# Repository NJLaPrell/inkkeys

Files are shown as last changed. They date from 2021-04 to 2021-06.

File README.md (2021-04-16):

# inkkeys
Details and instructions can be found on https://there.oughta.be/a/macro-keyboard

In contrast to most of my other projects, I decided to put this into its own repository as it is slightly more complex and I am hoping for community contributions.

If you have pull-requests, bug reports or want to contribute new case designs, please do not hesitate to open an issue. For generic discussions, "show and tell" and if you are looking for support for something that is not a problem in the code here, I would recommend [r/thereoughtabe on reddit](https://www.reddit.com/r/thereoughtabe/).

## Mac Install
Installing on the mac requires several dependencies, some of which are not apparent without a little digging. In order for the AppKit dependency to properly compile, you must be using Python 3.3.* or higher. Note that pulse audio is linux only, so it must be commented/removed from the python code. You will not be able to install the dependency. The following commands should mostly put everything in order to run the controller.py script.

    brew install pkg-config
    brew install cairo
    pip3 install pillow
    pip3 install pyserial
    pip3 install psutil
    pip3 install AppKit
    pip3 install pyobjc

## Common problems

**NOTE:** This fork already has the changes below implemented.

### Display revision 2
Apparently, the original design used revision 1 of the display, while many newly ordered version are revision 2. There are a few differences and thankfully, [Corky402 made a good list of required changes on Reddit](https://www.reddit.com/r/arduino/comments/l4wxxf/the_hardware_is_assembled_and_passed_all_tests/gqovq1j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). 

Here is an excerpt of the original post for reference:
>If you want to test your display hooked to a Arduino or Raspberry Pi you need to run examples for the epd2in9_V2 not the epd2in9.
>
>To get this awesome project working there is no need to make any alterations to the PCB, just simply plumb the Waveshare up on the connectors as I describe, not as per Sebastian's original post.
>
>PCB Pin Waveshare wiring loom
>
>+5v Grey
>
>GND Brown
>
>DIN Blue
>
>CLK Yellow
>
>CS Orange
>
>DC Green
>
>RST Purple
>
>BUSY White
>
>In short you are swapping the RST & BUSY lines on the PCB.
>
>Next, go to your Arduino sketch. This is for the hardware-test script. Enable line numbering and go to line 43 which reads -
>
>GxEPD2_290 display(/*CS=*/ PIN_CS, /*DC=*/ PIN_DC, /*RST=*/ PIN_RST, /*BUSY=*/ PIN_BUSY);
>
>Change this to -
>
>GxEPD2_290_T94 display(/*CS=*/ PIN_CS, /*DC=*/ PIN_DC, /*RST=*/ PIN_RST, /*BUSY=*/ PIN_BUSY);
>
>Then go to settings.h
>
>Lines 2 - 7 need to be altered so change that section of code as follows -
>
>const byte PIN_DIN = 16;
>
>const byte PIN_CLK = 15;
>
>const byte PIN_CS = 19;
>
>const byte PIN_DC = 18;
>
>const byte PIN_RST = 10;
>
>const byte PIN_BUSY = 14;
>
>The sketch will then compile and when uploaded to the board you will get the Waveshare drawing all sorts of Austin Powers time machine circles that make your eyes spin! 

### Alternate Neopixels ###
If a different LED is substituted for the PL9823, the usage in the led.ino file and hardware-test.ino file may be different. For the APA106 LED, the NeoPixels are initialized this way:

    Adafruit_NeoPixel leds = Adafruit_NeoPixel(N_LED, PIN_LED, NEO_GRB + NEO_KHZ800);

### Serial Hang ###
An instance using a Mac and the YeeKees Pro Micro controller encountered issues where sending binary data resulted in the Pro Micro no longer recieving  serial data (but sill sending). It is unknown at this time if the issue is how pyserial is implimented on Mac or a limitation of the YeeKees Pro Micro controller (two different controllers yielded the same issue). The workaround is to chunk the byte data and send it 100 bytes at a time.

### E-Ink Display Issues ###
E-ink display renders icons faded in some cases and missing pixels in others. Cause is unknown at this time and may be related to timing. 

## Gallery

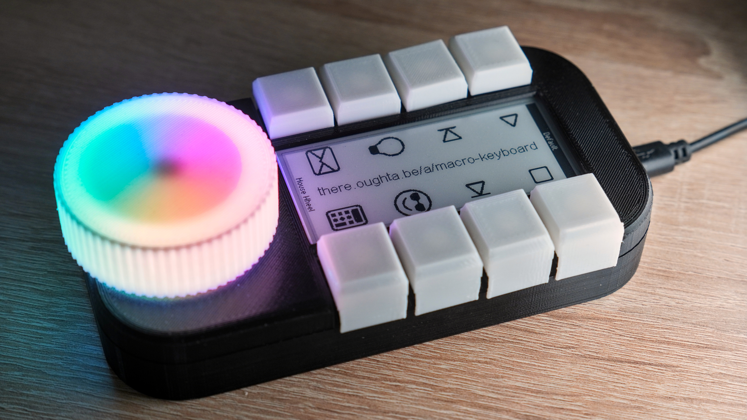
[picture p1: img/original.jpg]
Original design Original design as presented on there.oughta.be with the 3d printing files from this repository.

Original design as presented on there.oughta.be with the 3d printing files from this repository.

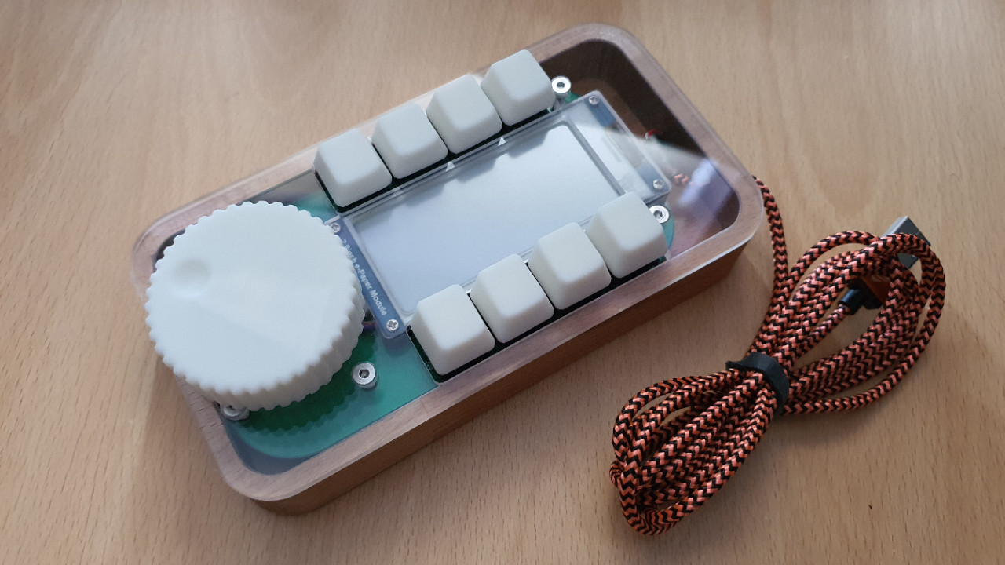
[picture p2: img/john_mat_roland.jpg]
Original design Design by John, Mat and Roland from the UK. The case was CNC milled from beech with a similarly machined clear perspex lid.

Design by John, Mat and Roland from the UK. The case was CNC milled from beech with a similarly machined clear perspex lid.

## Fork Notes ##
This fork uses a KeeYees brand Pro Micro controller and APA106 LEDs which are different from the original specs. The python code is also run on a Mac and has been updated to rotate the display 90 degrees so that the device can be rotated on it's side. This is a work in progress.

### Known Issues ###
 - The text for the title must have a minimum height of 40 or the controller goes unresponsive and responds with unknown characters when the display is refreshed.
 - Resending images often times out and has the effect of fading the current display when the display is shut down.

### TODO ###
 - Re-impliment the icon overlays.
 - Re-impliment the ability to use text instead of icons.
 - Add the ability to place text above/below the icons.

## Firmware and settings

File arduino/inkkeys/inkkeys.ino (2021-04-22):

/*
 * E-Ink adaptive macro keyboard
 * See https://there.oughta.be/a/macro-keyboard
 * 
 * This is the main code which acts as a HID keyboard while
 * allowing to be controlled through a serial interface.
 */

#include "settings.h"           //Customize your settings in settings.h!

#include "eventsequence.h"      //Structure and constants to define the sequence of events assigned to different buttons
#include <HID-Project.h>        //HID (Keyboard/Mouse etc.)
#include <Encoder.h>            //Rotary Encoder
#include <GxEPD2_BW.h>          //E-Ink Display
#include <Adafruit_NeoPixel.h>  //Digital RGB LEDs

//Keys
const byte nSW = 9;
const byte SW[] = {PIN_SW1, PIN_SW2, PIN_SW3, PIN_SW4, PIN_SW5, PIN_SW6, PIN_SW7, PIN_SW8, PIN_SW9}; //Array of switches for easy iteration
bool pressed[] = {false, false, false, false, false, false, false, false, false}; //Last state of each key to track changes
uint32_t swDebounce[] = {0L, 0L, 0L, 0L, 0L, 0L, 0L, 0L, 0L};

//Rotary encoder
Encoder rotary(PIN_ROTA, PIN_ROTB);
long rotaryPosition = 0;  //Last position to keep track of changes

//Display
//GxEPD2_290 display(/*CS=*/ PIN_CS, /*DC=*/ PIN_DC, /*RST=*/ PIN_RST, /*BUSY=*/ PIN_BUSY);
GxEPD2_290_T94 display(/*CS=*/ PIN_CS, /*DC=*/ PIN_DC, /*RST=*/ PIN_RST, /*BUSY=*/ PIN_BUSY);
//GxEPD2_290_T94<GxEPD2_290_T94, GxEPD2_290_T94::HEIGHT> display(GxEPD2_290_T94(/*CS=*/ PIN_CS, /*DC=*/ PIN_DC, /*RST=*/ PIN_RST, /*BUSY=*/ PIN_BUSY));
void initDisplay() {
  display.init(115200, true, 1, false);
  display.writeScreenBuffer();
  display.refresh();
  display.writeScreenBufferAgain();
  display.powerOff();
}

void setup() {
  initLEDs();
  //Initialize LEDs first, for some reason they initialize blue
  //  after a power cycle which is pretty annoying.
  
  Serial.begin(115200);

  defaultAssignment();

  //Greeting on serial
  Serial.println("= InkKeys =");
  
  //Set pin modes for keys
  for (int i = 0; i < nSW; i++) {
    pinMode(SW[i], INPUT_PULLUP);
  }

  //Set rotary encoder to zero
  rotary.write(rotaryPosition);

  //Init e-ink screen, clear it and turn it off.
  initDisplay();

  //Init HID.
  //These three should provide most desired functions and as the 32u4
  //on the Pro Micro provides 6 endpoints (-1 for serial), we can
  //use the single report variants for compatibility.
  BootKeyboard.begin();
  BootMouse.begin();
  SingleConsumer.begin();

  //Show LED greeting to confirm completion
  animateLeds(1, 800, 10, 0, (0, 0, 0), 1);
  Serial.println("Ready.");
}

void loop() {
  processAnimation();
  checkKeysAndReportChanges();
  checkRotaryEncoderAndReportChanges();
  handleSerialInput();
}

//Called when state of key has changed. Checks debounce time
//and returns false if event should be filtered. Otherwise it
//returns true and resets the debounce timer.
bool debounce(byte i) {
  long t = millis();
  if (t - swDebounce[i] < DEBOUNCE_TIME)
    return false;
  else {
    swDebounce[i] = t;
    return true;
  }
}

//Check if keys have changed and report any changes
void checkKeysAndReportChanges() {
  for (int i = 0; i < nSW; i++) {
    int state = digitalRead(SW[i]);
    if (state == LOW && !pressed[i]) {
      if (debounce(i)) {
        pressed[i] = true;
        Serial.print(i+1);
        Serial.println("p");
        executeEvents(assignments[i][0]);
      }
    } else if (state == HIGH && pressed[i]) {
      if (debounce(i)) {
        pressed[i] = false;
        Serial.print(i+1);
        Serial.println("r");
        executeEvents(assignments[i][1]);
      }
    }
  }
}

//Check if rotary encoder position changed and report any changes
void checkRotaryEncoderAndReportChanges() {
  long rotaryNew = rotary.read();
  if (abs(rotaryNew - rotaryPosition) >= ROT_FACTOR) {
    int report = (rotaryNew-rotaryPosition)/ROT_FACTOR;
    Serial.print("R");
    Serial.println(report);
    rotaryPosition += report*ROT_FACTOR;
    for (int i = 0; i < report; i++)
      executeEvents(assignments[9][0]);
    for (int i = 0; i < -report; i++)
      executeEvents(assignments[9][1]);
  }
}

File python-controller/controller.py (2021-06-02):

SERIALPORT = None #None = Auto-detect, to specify a specific serial port, you can set it to something like "/dev/ttyACM0" (Linux) or "COM1" (Windows)
VID = 0x1B4F      #USB Vendor ID for a Pro Micro
PID = 0x9206    #USB Product ID for a Pro Micro
DEBUG = True     #More output on the command line
HTTP_PORT = 8080

from inkkeys import *        #Inkkeys module
from processchecks import *  #Functions to check for active processes and windows
from modes import *          #Definitions of the hotkey functions in different "modes"

import time                         #Time functions
from serial import SerialException  #Serial functions
import serial.tools.list_ports      #Function to iterate over serial ports
import re                           #Regular expressions process name matching
import traceback                    #Print tracebacks if an error is thrown and caught
import socket                       #Get the hostname of the computer

import json
import threading                    #Run an http server in a separate thread.
from http.server import HTTPServer, BaseHTTPRequestHandler
from json import JSONDecodeError

print("https://there.oughta.be/a/macro-keyboard")
print('I will try to stay connected. Press Ctrl+c to quit.')

class HttpHandler(BaseHTTPRequestHandler):  
    def do_POST(self):
        content_length = int(self.headers["Content-Length"])
        post_data = self.rfile.read(content_length)
        if DEBUG:
            print(f"POST - {content_length} bytes received.")
        try:
            payload = json.loads(str(post_data, "utf-8"))
            if "status" in payload:
                device.setStatus(payload["status"])

            self.send_response(200)
            self.send_header("Content-type", "text/plain")
            self.end_headers()
        except JSONDecodeError as jde:
            print(jde)
            print(post_data)
            self.send_response(200)
            self.send_header("Content-type", "text/plain")
            self.end_headers()

def listenToHttp():
    print(f'Listening for http traffic on port {HTTP_PORT}')
    try:
        httpd = HTTPServer(("0.0.0.0", HTTP_PORT), HttpHandler)
        httpd.serve_forever()
    except OSError:
        print(f"Cannot bind http server on adress {HTTP_PORT}")

httpThread = threading.Thread(target=listenToHttp, daemon=True)
httpThread.start()



############################################################################################################

#This is the main part, which reassigns keys, sets the content of the display and updates the LEDs.
#The logic of this is built around "modes". The modes themselves are defined in "modes.py", where you can
#change key assignments, images, LED animations and their entire logic.

#Below, you only define a list of modes (defined in "modes.py") that are active and set either a process
#(mode would be active whenever the process runs) or an active window (mode is active if the window has
#the focus. The latter is a compiled regular expression pattern. Mode priority corresponds to the order in the
#list, so the first mode with a matching process or active window will be activated.

modes = [\
            {"mode": ModeBlender(), "activeWindow": re.compile("^Blender")}, \
            {"mode": ModeGimp(), "activeWindow": re.compile("^GIMP.*")}, \
            {"mode": ModeMiniFallback(), "hostname": re.compile("^Mac-Min.*")}, \
            {"mode": ModeFallback()} \
        ]

hostname = socket.gethostname()

############################################################################################################

# Usually there should not be anything to be customized below this point

############################################################################################################

#If we found the device, successfully connected and retreived its information, we enter this work function,
#which primarily consists of an infinite loop that only returns if we hit Ctrl+C (or kill the process).

def work():
    mode = None             #Current mode of the device (i.e. key mappings for specific process).
    pollInterval = 0        #Polling interval as requested by the module when the last call to "poll" was made
    lastPoll = 0            #Keeps track of the last time the poll function of the mode instance was called
    lastProcessList = 0     #Keeps track of the last time the list of processes was retrieved
    lastModeCheck = 0       #Keeps track of the last time the current window was checked and a decision about the mode was made
    activeWindow = None
    
    try:
        while True:     #Now we are in our main, infinite loop -------------------
            now = time.time() #Time of this iteration

            if now - lastProcessList > 5.0:      # Only check the process list every 5 seconds.
                processes = getActiveProcesses() # This is a surprisingly expensive and slow call, so don't overdo as it might prevent smooth LED animation (fixable by implementing a second thread) and burn more CPU resources than you might want from a background process
                lastProcessList = now

            if now - lastModeCheck > 0.5:       # Check active window and decide which mode to use. This can be done more regularly, but since the e-ink screen takes a moment to update, it does not make sense to check more frequently
                window = getActiveWindow()      # Get the currently active window
                if window != None:              # Sometime getting the active window fails, then ignore it. (Some window managers allow having no window in focus)
                    if DEBUG and activeWindow != window:                   #Enable DEBUG to see the actual name of the current window if you need it to match your modules
                        print("Active window: " + str(window))
                    activeWindow = window
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

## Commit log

2021-04-03 Included pin change for v2 display.
2021-04-03 Pin change in both settings files for v2 display...
2021-04-03 Changed LED to APA106 instead of PL9823.
2021-04-03 Change solder mask and added gbr files generated for the PCB ordered through JLCPCB.
    [inkkeys-B_Mask.gbr, inkkeys-B_Paste.gbr, inkkeys-B_SilkS.gbr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]
2021-04-13 Resolved serial hang and some display issues.
    [controller.py, device.py, modes.py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]
2021-04-14 Progress fixing display ghosting. Start of modifications for my own use.
    [controller.py, device.py, inkkeys.ino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]
2021-04-14 More button assignments
2021-04-21 Fixed mode detection for hostname. Updated the way the screen is cleared when switching hosts. Defaulted refreshDisplay not to rewrite back to the buffer when no partial refreshes will happen later.
    [controller.py, device.py, serialinput.ino]
2021-04-22 Converting LED animation to be non-blocking.
2021-04-22 Added step delay for animations. Added function to call LED animations from python. Added blue blink when changing modes.
2021-04-22 Display tweaks. LED Animation enhancements.
2021-04-23 Added an http server and the ability to set a global status value and trigger LED animations. Needs cleanup.
